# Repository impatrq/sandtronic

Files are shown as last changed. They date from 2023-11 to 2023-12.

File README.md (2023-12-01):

<div align="center">

# **SandTronic**
<div align="center">
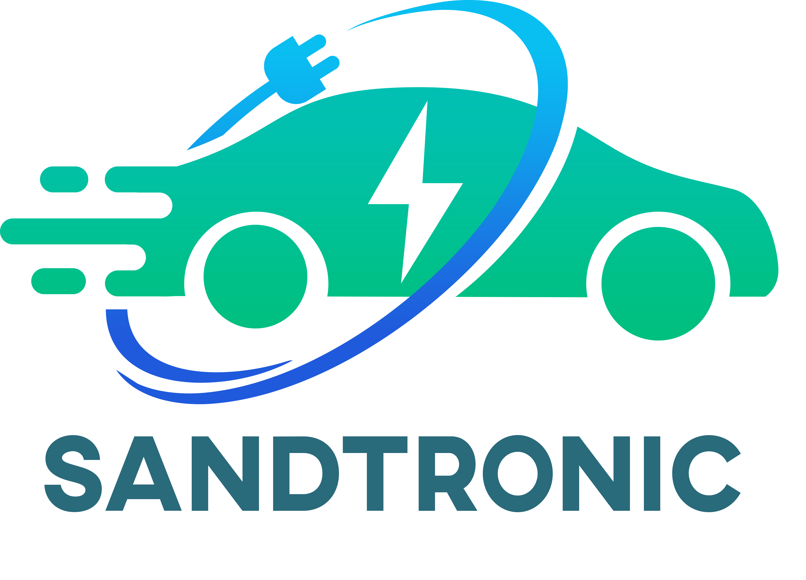
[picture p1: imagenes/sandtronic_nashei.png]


</div>

# ¿Qué es SandTronic?
Es un karting eléctrico especialmente adaptado para su uso en playas, con el propósito de brindar un medio de transporte eficiente y seguro para situaciones de emergencia en las que los guardavidas necesiten rescatar a personas en peligro en el agua o en áreas remotas de la playa.

## ¿Quienes somos?

#### Somos un grupo de estudiantes de aviónica de la E.E.S.T. N°7 "Taller Regional Quilmes", conocida como IMPA.

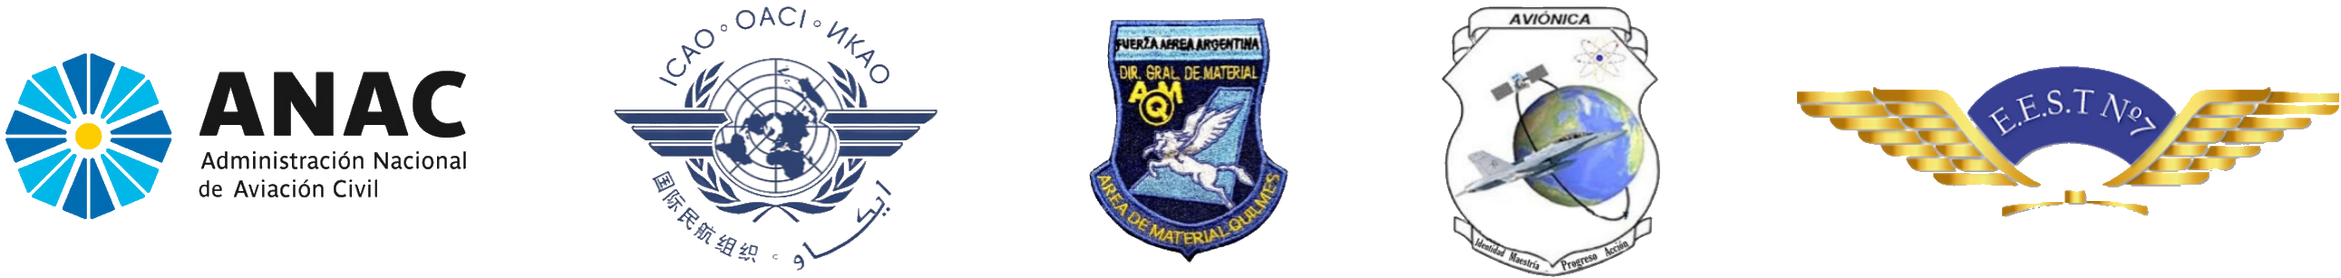
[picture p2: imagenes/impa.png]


# Integrantes

* ###  *Alvarez, Mauricio*
    *    📧 Email: [maurialvarez2004@gmail.com](mailto:maurialvarez2004@gmail.com)         

* ### *Enricci Louzan, Carla*
    *    📧 Email: [carlamicaela2004@gmail.com](mailto:carlamicaela2004@gmail.com)
    *    LinkedIn LinkedIn: [Carla Enricci](https://www.linkedin.com/in/carla-micaela-enricci-louzan/)

* ###  *Morellato, Nicolas*
    *    📧 Email: [morellatonico@gmail.com](mailto:morellatonico@gmail.com)

* ### *Vega Ezequiel*
    *    📧 Email: [ezevega44@gmail.com](mailto:ezevega44@gmail.com)

* ### *Zanichelli, Mateo*
    *  📧 Email: [mateo.zanichelli@hotmail.com](mailto:mateo.zanichelli@hotmail.com)
    *    LinkedIn LinkedIn: [Mateo Zanichelli](https://www.linkedin.com/in/mateo-zanichelli-b1b2b827b/)

<div align="center">
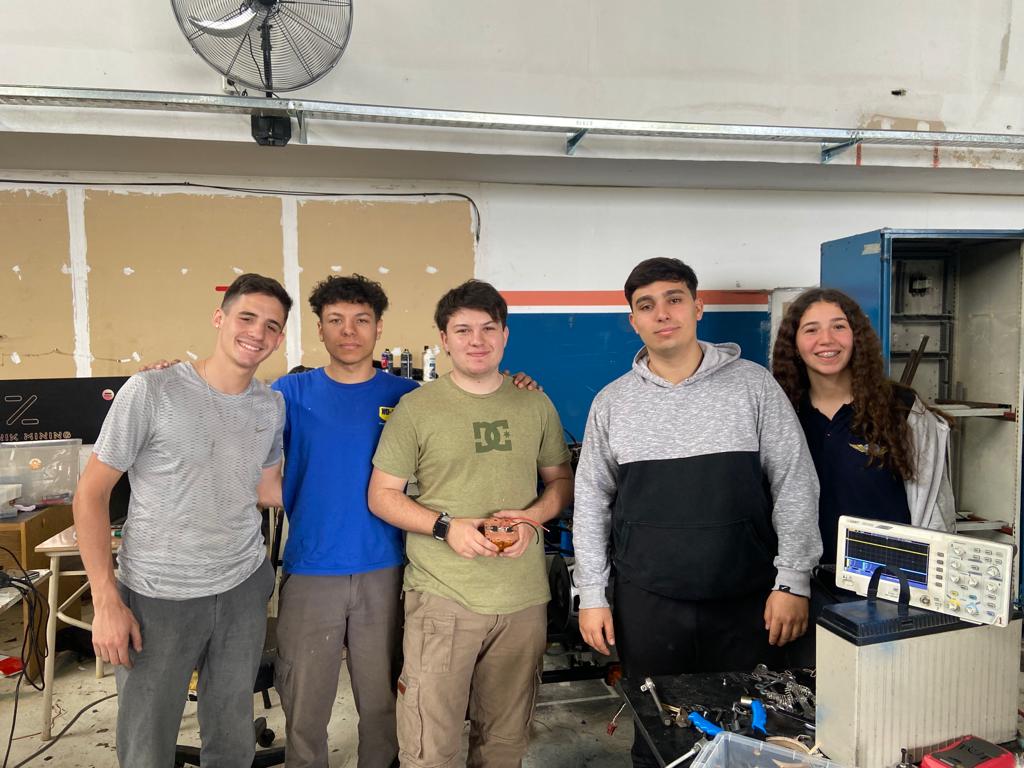
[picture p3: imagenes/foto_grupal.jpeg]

</div>

## ¿Dónde nos pueden encontrar?
### 📷Instagram: [@SandTronic_gr](https://instagram.com/sandtronic_gr?igshid=NzZlODBkYWE4Ng==)
### LinkTree: [SandTronic](https://linktr.ee/sandtronic_gr)
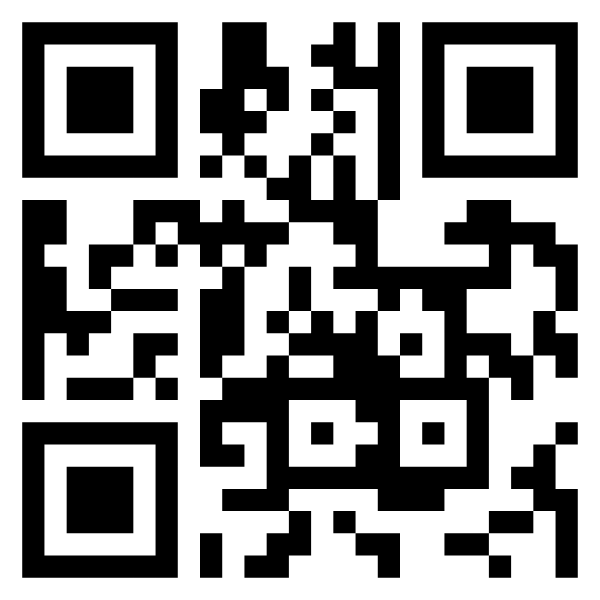
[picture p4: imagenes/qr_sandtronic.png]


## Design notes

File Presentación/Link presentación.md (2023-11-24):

[Dar click para ver presentación](https://www.canva.com/design/DAF0_eJnGpE/yYKZw175jgtaCtqbcVzkhw/view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)

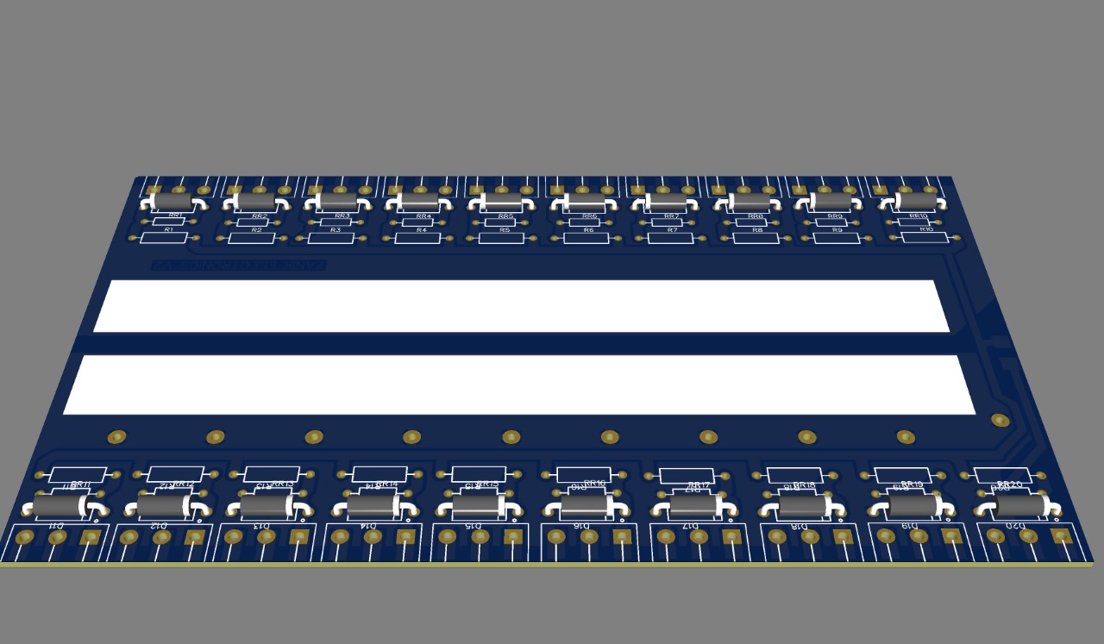
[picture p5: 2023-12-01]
electronica/placa _potencia_3D.jpeg

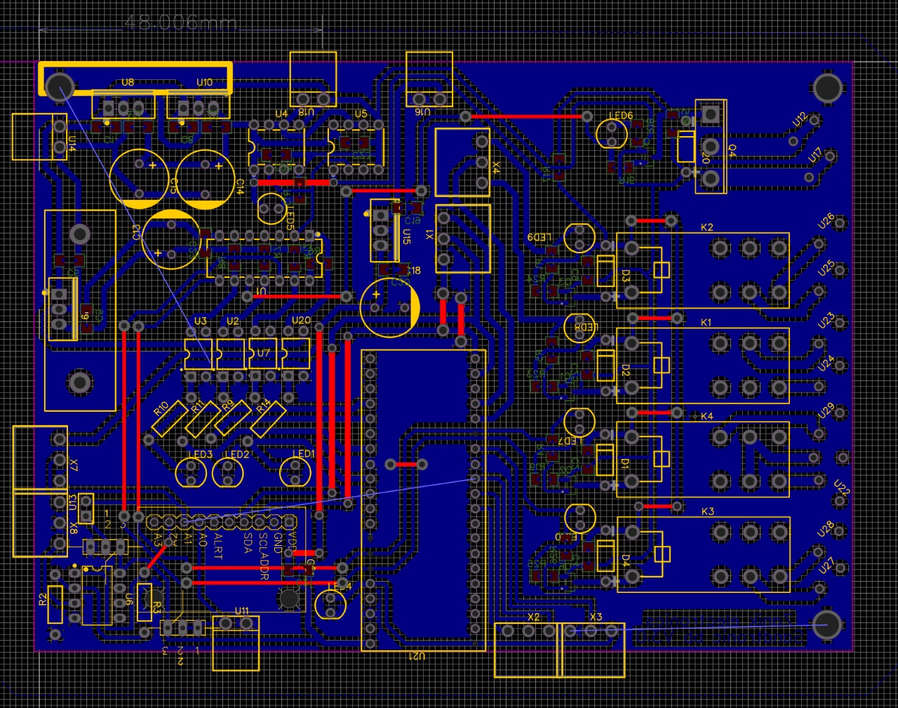
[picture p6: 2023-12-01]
electronica/placa_control_pcb.jpg

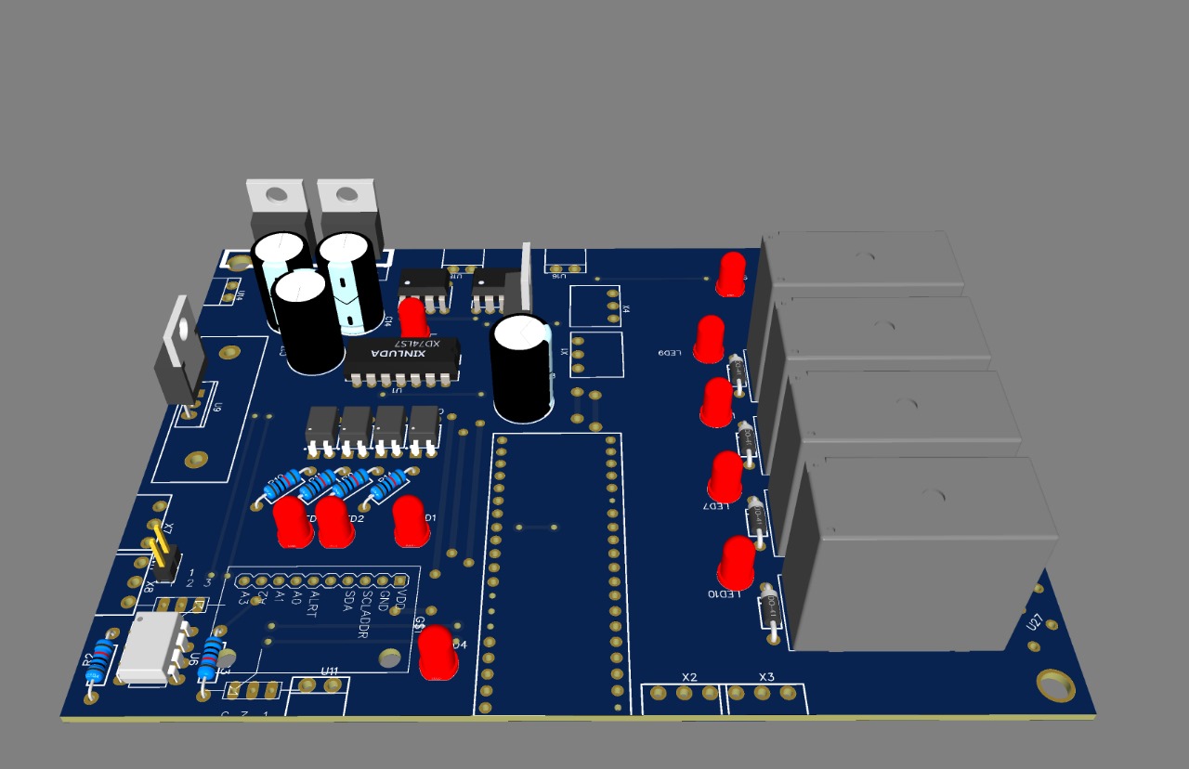
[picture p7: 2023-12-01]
electronica/placa_control_3D.jpeg

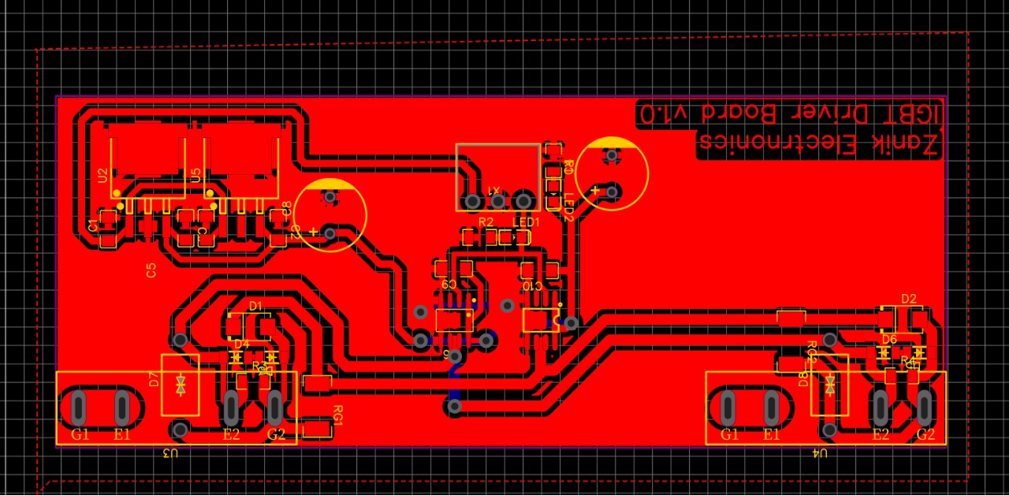
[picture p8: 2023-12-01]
electronica/placa_potencia_pcb.jpg

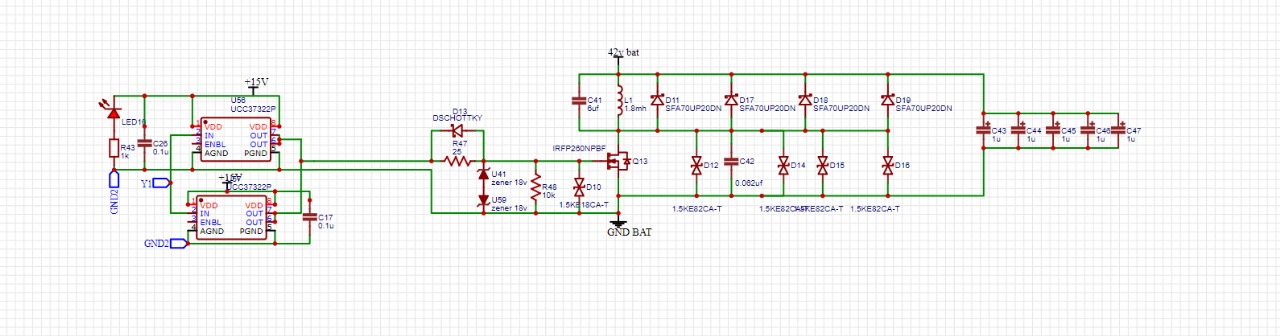
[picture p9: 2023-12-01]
electronica/potencia_schematic_nuevo.jpg

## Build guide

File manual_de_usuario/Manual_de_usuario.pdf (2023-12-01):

# MANUAL DE USUARIO SANDTRONIC

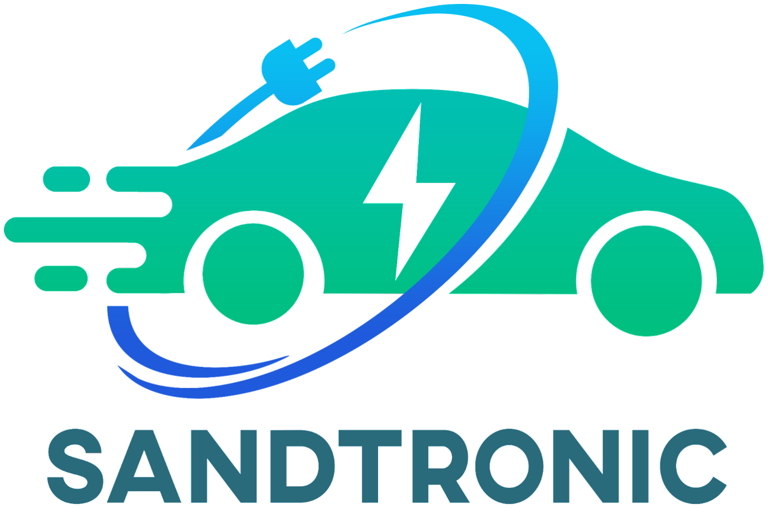
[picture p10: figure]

### E.E.S.T. N°7 “T.R.Q.” Juan B. Justo 79, Quilmes eoffroad2023@gmail.com

2023

# Contenido

I. Introducción
1.Objetivo.

II. Precauciones y seguridad 1.Requerimientos
2.Seguridad

III. Guia de uso

### 1. Encendido del arenero electrico 2. Modos de conducción

I. Introducción

### 1. Objetivo

Principalmente Sandtronic tiene como objetivo diseñar, desarrollar y poner en funcionamiento un karting eléctrico especialmente adaptado para su uso en playas, con el propósito de proporcionar un medio de transporte eficiente y seguro para situaciones de emergencia en las que los guardavidas necesiten rescatar a personas en peligro en el agua o en áreas remotas de la playa.

II.Precauciones y seguridad

### 1. Requerimientos

- Que las baterías se encuentren cargadas (Estas deben tener 12,8V)
- Mantener los ciclos de carga de la batería por encima del 60%
- Evita descargar completamente la batería siempre que sea posible. Las descargas completas frecuentes pueden afectar la vida útil.
- Asegúrate de que el conector de carga esté limpio y en buen estado para garantizar una conexión segura y eficiente.
- Sistema de frenos: Verifica regularmente el estado de los frenos y el nivel del fluido.
- Evita sobrecargas: no sobrecargues la batería, ya que esto puede
dañarla y reducir su vida útil
- Neumáticos: Presión máxima de los neumáticos: 10PSI

### 2. Seguridad

- Instrucciones de Uso: Familiarízate completamente con el manual del usuario y sigue las instrucciones cuidadosamente.
- Equipos de Protección: Siempre usa casco, gafas de protección, guantes y ropa adecuada al andar en el arenero.
- Supervisión: Se recomienda supervisión de alguien con experiencia mientras un conductor inexperto utiliza el arenero.
- Mantenimiento Regular: Realiza revisiones periódicas y mantenimiento según las indicaciones del manual para garantizar un rendimiento seguro.
- Carga Máxima: Respete la capacidad de carga máxima del vehículo(220KG).

III. Guia de uso

### 1. Encendido del arenero electrico

A- Inspección Previa:

Antes de cada uso, realiza una inspección visual del arenero para asegurarte de que no haya daños visibles. Verifica que los neumáticos estén inflados correctamente.

B- Ajustes del Asiento y Cinturón de Seguridad:

Ajusta el asiento a una posición cómoda y asegúrase de abrocharse el cinturón de seguridad antes de comenzar la conducción

C- Encendido:

Mantenga pulsado el botón START durante tres segundos, luego ponga el interruptor en ON

D- Arranque Suave:

Al iniciar, presione el acelerador suavemente para evitar arranques bruscos. Familiarízate con la respuesta del vehículo.

E- Maniobras Seguras:

Evitar giros bruscos y maniobras riesgosas. Aprende a girar y maniobrar de manera controlada.

F- Carga y Capacidad

Respeta la capacidad de carga máxima especificada en el manual del usuario(220KG).
Distribuye la carga de manera uniforme para mantener la estabilidad.

### 2. Modos de conducción

Sandtronic cuenta con dos modos de conducción

MODO SPORT: En este modo el karting tiene una autonomía de 28 KM

MODO ECO: En este modo el karting tiene una autonomía de 42 KM

Ambos modos lo podremos seleccionar con una llave selectora que se encuentra a la izquierda del tablero.

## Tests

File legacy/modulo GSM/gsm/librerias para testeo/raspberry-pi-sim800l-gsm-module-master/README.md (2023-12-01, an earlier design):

# Raspberry Pi SIM800L GSM module






[SIM800L GSM module](https://www.simcom.com/product/SIM800.html) library for Linux systems like the Raspberry Pi.

This library interfaces the SIM800L GSM device and allows sending, receiving and deleting SMS messages, as well as performing HTTP GET/POST requests, synching/updating the RTC and getting other information from the module.

## Setup

## Hw Requirements
- Linux system with a UART serial port, or Raspberry Pi with [Raspberry Pi OS](https://en.wikipedia.org/wiki/Raspberry_Pi_OS) (this library has been tested with Buster and Bullseye).
- External power supply for the SIM800L (using the Raspberry Pi 5V power supply, a standard diode (1N4007) with voltage drop of about 0.6 volts and a 2200 uF capacitor might work).

### Installation

Check that the [Python](https://www.python.org/) version is 3.6 or higher (`python3 -V`), then install the *sim800l-gsm-module* with the following command:

```shell
python3 -m pip install sim800l-gsm-module
```

Prerequisite components: *pyserial*, *gsm0338*. All needed prerequisites are automatically installed with the package.

Alternatively to the above mentioned installation method, the following steps allow installing the latest version from GitHub.

- Optional preliminary configuration (if not already done):

  ```shell
  sudo apt-get update
  sudo apt-get -y upgrade
  sudo add-apt-repository universe # this is only needed if "sudo apt install python3-pip" fails
  sudo apt-get update
  sudo apt install -y python3-pip
  python3 -m pip install --upgrade pip
  sudo apt install -y git
  ```

- Run this command:

```shell
  python3 -m pip install git+https://github.com/Ircama/raspberry-pi-sim800l-gsm-module
```

To uninstall:

```shell
python3 -m pip uninstall -y sim800l-gsm-module
```

### Hardware connection

sim800l

### Disabling the serial console login

Disabling the serial console login is needed in order to enable communication between the Raspberry Pi and SIM800L via /dev/serial0.

- Open the terminal on your pi and run `sudo raspi-config` 
- Select Interfaces → Serial 
- Select No to the 1st prompt and Yes for the 2nd one.

## Basic use

Check [Usage examples](#usage-examples). Basic program:

```python 
from sim800l import SIM800L
sim800l = SIM800L()
sim800l.setup()
print("Unit Name:", sim800l.get_unit_name())
```

## API Documentation

Tested with SIM800L firmware Revision:[1418B05SIM800L24](https://github.com/geekmatic/SIM800_firmware_updates) (SIM800L R14.18, Build 05).

SIM800 does not support AT+HTTPSSL on firmware release <R14.00 (e.g., 1308B08SIM800L16 -> SIM800L R13.08 Build 08).

For debugging needs, logs can be set to the maximum level (verbose mode, tracing each request/response) with the following command:

```python
import logging
logging.getLogger().setLevel(5)`
```

---

#### `sim800l = SIM800L(port='/dev/serial0', baudrate=115000, timeout=3.0)`
Class instantiation (using [pySerial](https://github.com/pyserial/pyserial))
- `port`: port name
- `baudrate`: baudrate in bps
- `timeout`: timeout in seconds

---

#### `check_sim()`
Check whether the SIM card has been inserted.
 *return*: `True` if the SIM is inserted, otherwise `False`. `None` in case of module error.

---

#### `command(cmdstr, lines=1, waitfor=500, msgtext=None, flush_input=True)`
Executes an AT command. A newline must be added at the end of the AT command (e.g., `sim800l.command("AT+CCLK?\n", lines=-1)`).
Input is flushed before sending the command (`flush_input=False` disables flushing).
The first newline is discarded (if `lines` != 0).
- `cmdstr`: AT command string
- `lines`: number of expexted lines (see below)
- `waitfor`: number of (milliseconds - 1000) to wait for the returned data; not used if <= 1000 milliseconds.
- `msgtext`: only to be used when sending SMS messages, it includes the SMS text.
- `flush_input`: `True` if residual input is flushed before sending the command. `False` disables flushing.

 *return*: the first line is returned (string); use `check_incoming()` to read the subsequent lines. `None` is returned when no data is received (or module error).

If `lines=0`, terminates just after writing text to the device (no bytes read; no return code, e.g. `None` returned). Note: `check_incoming()` can be subsequently used to read data from the device (see subsequent example).

If `lines`<0 (e.g., `lines=-1`), return the concatenation of all read lines (until pySerial timeout `sim800l.serial_port().timeout`), separating each line by a linefeed.

If `lines`>1 (legacy code), return the concatenation of all read lines, separating each line by a linefeed, discarding null lines and "OK".

Example:

```python
import time
from sim800l import SIM800L

sim800l=SIM800L('/dev/serial0')

# Send data and return the first line
print(sim800l.command("AT+CCLK?\n"))  # ...+CCLK...

# Same as before, but reading both lines
sim800l.command("AT+CCLK?\n", lines=0)  # send AT command without reading data
print("First read line:", sim800l.check_incoming())  # ...+CCLK...
print("Second read line:", sim800l.check_incoming())  # ...'OK'...

# Same as before, but more elaborated
sim800l.command("AT+CCLK?\n", lines=0)
expire = time.monotonic() + 2  # seconds
sequence = ""
s = sim800l.check_incoming()
date = None
while time.monotonic() < expire:
    if s[0] == 'GENERIC' and s[1] and s[1].startswith('+CCLK: "'):
        date = s[1].split('"')[1]
        sequence += "D"
    if s == ('OK', None):
        sequence += "O"
    if sequence == "DO":
        print("Date:", date)
        break
    time.sleep(0.1)
    s = sim800l.check_incoming()

if not date:
    print("Error")
```

---

#### `command_data_ok(cmd, attempts=2)`
Send AT command to the device, read the answer and then check the
existence of the OK message. "cmd" shall not have the ending newline.
- `cmd`: AT command
- `attempts`: number of attempts before returning None or False
 *return*: string in case of successful retrieval; otherwise None if module error or False if missing OK message

---

#### `command_ok(cmd, check_download=False, check_error=False, cmd_timeout=10, attempts=2)`
Send AT command to the device and check that the return sting is OK.
Newline must not be put at the end of the string.
- `cmd`: AT command
- `check_download`: `True` if the “DOWNLOAD” return sting has to be checked
- `check_error`: `True` if the “ERROR” return sting has to be checked
- `cmd_timeout`: timeout in seconds
- `attempts`: number of attempts before returning False
 *return*: `True` = OK received, `False` = OK not received (or module error). If check_error, can return `ERROR`; if check_download, can return `DOWNLOAD`

---

#### `connect_gprs(apn=None)`
Connect to the bearer and get the IP address of the PDP context.
Automatically perform the full PDP context setup.
Reuse the IP session if an IP address is found active.
- `apn`: APN name
 *return*: `False` if error (including module error), otherwise return the IP address (as string)

---

#### `delete_sms(index_id)`
Delete the SMS message referred to the index
- `index_id`: index in the SMS message list starting from 1
 *return*: `None`

---

#### `disconnect_gprs(apn=None)`
Disconnect the bearer.
 *return*: `True` if succesfull, `False` if error

---

#### `get_battery_voltage()`
Return the battery voltage in Volts
 *return*: floating (volts). `None` in case of module error.

Example: 4.158

---

#### `get_ccid()`
Get the ICCID
 *return*: string; `None` in case of module error.

Example: "1122334455667788990f"

---

#### `get_date()`
Return the clock date available in the module.
 *return*: `datetime.datetime`; `None` in case of module error.

Example: "2022-03-09 19:59:31"

---

#### `get_flash_id()`
Get the SIM800 GSM module flash ID
 *return*: string; `None` in case of module error.

Example: "Device Name:SERIAL§FLASH§MTKSIP§6261§SF§24§01"

---

#### `get_hw_revision()`
Get the SIM800 GSM module hw revision
 *return*: string; `None` in case of module error.

Example: "Revision:1418B05SIM800L24"

---

#### `get_imsi()`
Get the IMSI
 *return*: string; `None` in case of module error.

Example: "112233445566778"

---

#### `get_ip()`
Get the IP address of the PDP context
 *return*: valid IP address string if the bearer is connected, otherwise `None` (e.g., module error).

---

#### `get_msgid()`
Return the unsolicited notification of incoming SMS
 *return*: number

---

#### `get_msisdn()`
Get the MSISDN subscriber number
 *return*: string. `None` in case of module error.

---

#### `get_operator()`
Display the current network operator that the handset is currently
registered with.
 *return*: operator string. `None` in case of module error. `False` in case of SIM error.

Example: "Vodafone"

---

#### `get_operator_list()`
Display a full list of network operator names.
 *return*: dictionary of "numeric: "name" fields; None in case of error.

---

#### `get_serial_number()`
Get the SIM800 GSM module serial number
 *return*: string; `None` in case of module error.

Example: "866782042319455"

---

#### `get_service_provider()`
Get the Get Service Provider Name stored inside the SIM
 *return*: string. `None` in case of module error. `False` in case of SIM error.

---

#### `get_signal_strength()`
Get the signal strength
 *return*: number; min = 3, max = 100; `None` in case of module error.

Example: 40.625

---

#### `get_temperature()`
Get the SIM800 GSM module temperature in Celsius degrees
 *return*: string; `None` in case of module error.

Example: "24.21"

---

#### `get_unit_name()`
Get the SIM800 GSM module unit name
 *return*: string (e.g., "SIM800 R14.18"); `None` in case of module error.

---

#### `hard_reset(reset_gpio)`
Perform a hard reset of the SIM800 module through the RESET pin.
This function can only be used on a Raspberry Pi.
- `reset_gpio`: RESET pin
 *return*: `True` if the SIM is active after the reset, otherwise `False`. `None` in case of module error.

---

#### `http(url="...", data="...", apn="...", method="...", use_ssl=False, ua=None, content_type="application/json", allow_redirection=False, http_timeout=10, keep_session=False, attempts=2)`
Run the HTTP GET method or the HTTP PUT method and return retrieved data
Automatically perform the full PDP context setup and close it at the end
(use keep_session=True to keep the IP session active). Reuse the IP
session if an IP address is found active.
Automatically open and close the HTTP session, resetting errors.
- `url`: URL
- `data`: input data used for the PUT method (bytes; e.g., use `data="string".encode()`)
- `apn`: APN name
- `method`: "GET" or "PUT"
- `use_ssl`: `True` if using HTTPS, `False` if using HTTP (see note)
- `ua`: User agent (string); is not set, the SIM800L default user agent is used ("SIMCOM_MODULE").
- `content_type`: (string) set the "Content-Type" field in the HTTP header
- `allow_redirection`: `True` if HTTP redirection is allowed (e.g., if the server sends a redirect code (range 30x), the client will automatically send a new HTTP request)
- `http_timeout`: timeout in seconds
- `keep_session`: `True` to keep the PDP context active at the end
- `attempts`: number of attempts before returning False
 *return*: `False` if error, otherwise the returned data (as string)

While the *Content type* header field can be set, the *Content encoding* is always null.

Sending data with [zlib](https://docs.python.org/3/library/zlib.html) is allowed:

```python
import zlib
body = zlib.compress('hello world'.encode())
sim800l.http("...url...", method="PUT", content_type="zipped", data=body, apn="...")
```

[Note on SSL](https://github.com/ostaquet/Arduino-SIM800L-driver/issues/33#issuecomment-761763635): SIM800L datasheets report that the embedded IP stack only supports SSL2, SSL3 and TLS 1.0. These cryptographic protocols are deprecated for all modern backend servers and the connection will be generally denied by the server, typically leading to SIM800L error 605 or 606 when establishing an HTTPS connection. Some SIM800L datasheets also report support of TLS 1.2 but this does not appear to be true with firmware Revision 1418B05SIM800L24.  So, using `use_ssl=True` is discouraged; setting a Python web server to support the SSL option of a SIM800L client module is not straightforward (it is better to use an [application encryption](https://stackoverflow.com/a/55147077/10598800) instead of SSL). Generally, to be able to connect an HTTPS web service, a separate proxy server is needed (e.g., a custom Python application in cloud), receiving non-SSL HTTP requests from the SIM800L module (possibly with application encryption) and forwarding them to the AWS Lambda HTTP API gateway via HTTPS.

Notice also that, depending on the web server, a specific SSL certificate could be needed for a successful HTTPS connection; the SIM800L module has a limited support of SSL certificates and [installing an additional one](https://stackoverflow.com/questions/36996479/how-sim800-get-ssl-certificate
) is not straightforfard.

An additional problem is related to possible DNS errors when accessing endpoints. Using IP addresses is preferred.

---

#### `internet_sync_time(time_server='193.204.114.232', time_zone_quarter=4, apn=None, http_timeout=10, keep_session=False)`
Connect to the bearer, get the IP address and sync the internal RTC with
the local time returned by the NTP time server (Network Time Protocol).
Automatically perform the full PDP context setup.
Disconnect the bearer at the end (unless keep_session = `True`)
Reuse the IP session if an IP address is found active.
- `time_server`: internet time server (IP address string)
- `time_zone_quarter`: time zone in quarter of hour
- `http_timeout`: timeout in seconds
- `keep_session`: `True` to keep the PDP context active at the end
 *return*: `False` if error, otherwise the returned date (`datetime.datetime`)

Example: "2022-03-09 20:38:09"

---

#### `query_ip_address(url=None, apn=None, http_timeout=10, keep_session=False)`
Connect to the bearer, get the IP address and query an internet domain
name, getting the IP address.
Automatically perform the full PDP context setup.
Disconnect the bearer at the end (unless keep_session = `True`)
Reuse the IP session if an IP address is found active.
- `url`: internet domain name to be queried
- `http_timeout`: timeout in seconds
- `keep_session`: True to keep the PDP context active at the end
 *return*: `False` if error (`None` for module error), otherwise the returned IP address (string)

---

#### `is_registered()`
Check whether the SIM is Registered, home network
 *return*: Truse if registered, otherwise `False`. . `None` in case of module error.

---

#### `read_and_delete_all(index_id=1)`
Read the message at position 1, otherwise delete all SMS messages, regardless the type (read, unread, sent, unsent, received).
If the message is succesfully retrieved, no deletion is done. (Deletion only occurs in case of retrieval error.)
Notice that, while generally message 1 is the first to be read, it might happen that no message at position 1 is available,
while other positions might still include messages; for those cases (missing message at position 1, but other messages
available at other positions), the whole set of messages is deleted.
Use `index_id=0` to delete all messages without trying to retrieve the one at position 1.
 *return*: text of the read message

---

#### `read_next_message(all_msg=False)`
Check messages, read one message and then delete it. This function can be repeatedly called to read all stored/received messages one by one and delete them.
- `all_msg`: `True` if no filter is used (read and unread messages).  Otherwise only the unread messages are returned.
 *return*: retrieved message text (string), otherwise: `None` = no messages to read; `False` = read error (module error)

---

#### `read_sms(index_id)`
Read the SMS message referred to the index_id position
- `index_id`: index in the SMS message list starting from 1
 *return*: `None` if error, otherwise return a tuple including: MSISDN origin number, SMS date string, SMS time string, SMS text

---

#### `send_sms(destno, msgtext)`
Send SMS message
- `destno`: MSISDN destination number
- `msgtext`: Text message
 *return*: `True` if message is sent, otherwise `False`

---

#### `serial_port()`
Return the serial port (for direct debugging)
 *return*:

---

#### `set_date()`
Set the Linux system date with the GSM time
 *return*: date string. `None` in case of module error.

Example: "2022-03-09 20:10:54"

---

#### `setup()`
Run setup strings for the initial configuration of the SIM800 module
 *return*: `True` if setup is successfully completed; `None` in case of module error.

---

#### `sim800l.convert_gsm(string)`
Encode `string` to bytes using the 3GPP TS 23.038 / ETSI GSM 03.38 codec.
- `string`: UTF8 string
 *return*: gsm03.38 bytes

---

#### `sim800l.convert_to_string(buf)`
Decode GSM 03.38 encoded bytes, returning a string.
- `buf`: gsm03.38 bytes
 *return*: UTF8 string

---

#### `check_incoming()`
Internal function, used to check incoming data from the SIM800L module, decoding messages.
It also fires the functions configured with `callback_msg()` and `callback_no_carrier()`.
 *return*: tuple

Return values:
- `('GENERIC', None)`: no data received
- `('GENERIC', data)`: received data is returned (`data` is a string)
- `("HTTPACTION_PUT", False, size)`: invalid HTTP PUT method, with return code different from 200
- `("HTTPACTION_PUT", True, size)`: valid HTTP PUT method; `size` is the number of returned characters
- `("HTTPACTION_GET", False, size)`: invalid HTTP GET method, with return code different from 200
- `("HTTPACTION_GET", True, size)`: valid HTTP GET method; `size` is the number of returned characters
- `("IP", "ip address")`: bearer connected, received IP address
- `("IP", None)`: Disconnected
- `("CMTI", index_id)`: received SMS message with index `index_id`
- `("NOCARRIER", None)`: "NO CARRIER" message detected
- `("RING", None)`: "RING" message detected
- `("OK", None)`: "OK" message detected
- `("DOWNLOAD", None)`: "DOWNLOAD" message detected
- `("ERROR", None)`: "ERROR" message detected
- `("DNS", None, error)`: DNS error message
- `("DNS", dns1, dns2)`: IP address and FQDN retrieved from the DNS
- `("NTP", None, error)`: NTP query error
- `("NTP", date, 0)`: Successful NTP query; `date` is `datetime.datetime` format
- `("COPN", numeric, name)`: Operator number and name
- `("CREG", numeric)`: Registration status
- `("CTZV", tz1, tz2)`: Time Zone
- `("PSUTTZ", year, month, day, hour, minute, second, tz1, tz2)`: time and time zone
- `("DST", dst)`: Daylight Saving Time
- `("RDY", None)`: Power procedure completed
- `("CFUN", numeric)`: Phone functionality indication
- `("PIN", pin)`: PIN
- `("MSG", "Call Ready)`: Call ready
- `("MSG", "SMS Ready)`: SMS ready

Usage sample 1:
```python
if self.check_incoming() != ("OK", None):
    print("Error")
```

---

#### `get_clip()`
(legacy code, not used)

---

#### `set_charset_hex()`
Set the module to the HEX character set (only hexadecimal values from 00 to FF)
 *return*: "OK" if successful, otherwise `None` in case of module error.

---

#### `set_charset_ira()`
Set the module to the International reference alphabet (ITU-T T.50) character set
 *return*: "OK" if successful, otherwise `None` in case of module error.

---

#### `callback_incoming(function)`
(legacy code, not used)
- `function`: Python function with no args

---

#### `callback_msg(function)`
(legacy code)
Configure a callback function, fired when `check_incoming()` receives a message (`+CMTI` returned, indicating new message received).
- `function`: Python function with no args

---

#### `callback_no_carrier(function)`
(legacy code)
Configure a callback function, fired when `check_incoming()` receives "NO CARRIER".
- `function`: Python function with no args

---

## Usage examples

```python 
from sim800l import SIM800L
sim800l = SIM800L('/dev/serial0')
```

#### Return module information
```python
from sim800l import SIM800L

sim800l = SIM800L()
sim800l.setup()

print("Date:",
    sim800l.get_date())
print("Operator:",
    sim800l.get_operator())
print("Service provider:",
    sim800l.get_service_provider())
print("Signal strength:",
    sim800l.get_signal_strength(), "%")
print("Temperature:",
    sim800l.get_temperature(), "degrees")
print("MSISDN:",
    sim800l.get_msisdn())
print("Battery Voltage:",
    sim800l.get_battery_voltage(), "V")
print("IMSI:",
    sim800l.get_imsi())
print("ICCID:",
    sim800l.get_ccid())
print("Unit Name:",
    sim800l.get_unit_name())

if sim800l.is_registered():
    print("SIM is registered.")
else:
    print("SIM NOT registered.")
```

#### Sync time with internet
```python
sim800l.internet_sync_time(apn="...", time_zone_quarter=...)
```

#### Query the DNS for an internet name
```python
sim800l.query_ip_address(url="httpbin.org", apn="...")
```

#### Hard reset
```python
# Note: connect the RST pin with GPIO23 (pin 16 of the Raspberry Pi)
sim800l.hard_reset(23)  # see schematics
```

#### Send SMS
```python
sms="Hello there"
#sim800l.send_sms(dest.no,sms)
sim800l.send_sms('2547xxxxxxxx',sms)
```

#### Read the next SMS message
```python
msg = sim800l.read_next_message(all_msg=True)
```

#### HTTP GET samples
```python
print(sim800l.http("httpbin.org/ip", method="GET", apn="..."))
print(sim800l.http("httpbin.org/get", method="GET", use_ssl=False, apn="..."))  # HTTP
print(sim800l.http("httpbin.org/get", method="GET", use_ssl=True, apn="..."))  # HTTPS
```

Note: time ago `httpbin.org` succeeded with HTTPS because supporting an old SSL version. Curently the test fails with HTTPS.

#### HTTP PUT sample
```python
print(sim800l.http("httpbin.org/post", data='{"name","abc"}'.encode(), method="PUT", apn="..."))  # HTTPS
print(sim800l.http("httpbin.org/post", data='{"name","abc"}'.encode(), method="PUT", use_ssl=False, apn="..."))  # HTTP
```

#### Read the n-th SMS
```python
Read the SMS indexed by the index_id value [ref. also check_incoming()]
index_id=...  # e.g., 1
sim800l.read_sms(index_id)
```

#### Callback action
(legacy code)
```python
def print_delete():
    # Assuming the SIM has no SMS initially
    sms = sim800l.read_sms(1)
    print(sms)
    sim800l.delete_sms(1)

sim800l.callback_msg(print_delete)

while `True`:
    sim800l.check_incoming()
```

## References
- [AT Datasheet](https://microchip.ua/simcom/2G/SIM800%20Series_AT%20Command%20Manual_V1.12.pdf)
- [Application notes](https://www.microchip.ua/simcom/?link=/2G/Application%20Notes)
- [Specifications](https://simcom.ee/documents/?dir=SIM800L)

Arduino:
- https://github.com/vshymanskyy/TinyGSM
- https://lastminuteengineers.com/sim800l-gsm-module-arduino-tutorial/

## History
This library is a fork of https://github.com/jakhax/raspberry-pi-sim800l-gsm-module with many additions.

The backward compatibility with the original repo is still kept.

> SIM900/SIM800 are 2G only modems, make sure your provider supports 2G as it is already being phased out in a lot of areas around the world, else a 3G/4G modem like the SIM7100 / SIM5300 is warranted.

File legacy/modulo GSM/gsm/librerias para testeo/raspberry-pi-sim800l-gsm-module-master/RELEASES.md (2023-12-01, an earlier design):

# Release process

Only tags are used by now (not releases).

# Tagging a release

If a version needs to be changed, edit `sim800l/__version__.py`.

This file is read by *setup.py*.

If the version is not changed, the publishing procedure works using the same version with a different build number.

The GITHUB_RUN_NUMBER environment variable, when available, is read by *setup.py*.

Push all changes:

```shell
git commit -a
git push
```

_After pushing the last commit_, add a local tag (shall be added AFTER the commit that needs to be published):

```shell
git tag # list local tags
git tag v0.1.4
```

Notes:

- correspondence between tag and `__version__.py` is not automatic.
- the tag must start with "v" if a GitHub Action workflow needs to be run

Push this tag to the origin, which starts the PyPI publishing workflow (GitHub Action):

```shell
git push origin v0.1.4
git ls-remote --tags https://github.com/Ircama/raspberry-pi-sim800l-gsm-module # list remote tags
```

Check the published tag here: https://github.com/Ircama/raspberry-pi-sim800l-gsm-module/tags

It shall be even with the last commit.

Check the GitHub Action: https://github.com/Ircama/raspberry-pi-sim800l-gsm-module/actions

Check PyPI:

- https://test.pypi.org/manage/project/sim800l-gsm-module/releases/
- https://pypi.org/manage/project/sim800l-gsm-module/releases/

End user publishing page:

- https://test.pypi.org/project/sim800l-gsm-module/
- https://pypi.org/project/sim800l-gsm-module/

Verify whether wrong builds need to be removed.

Test installation:

```shell
cd
python3 -m pip uninstall -y sim800l-gsm-module
python3 -m pip install sim800l-gsm-module
python3
from sim800l import SIM800L
quit()
python3 -m pip uninstall -y sim800l-gsm-module
```

# Updating the same tag (using a different build number for publishing)

```shell
git tag # list tags
git tag -d v1.0.0 # remove local tag
git push --delete origin v1.0.0 # remove remote tag
git ls-remote --tags https://github.com/Ircama/raspberry-pi-sim800l-gsm-module # list remote tags
```

Then follow the tagging procedure again to add the tag to the latest commit.

# Testing the build procedure locally

```shell
cd <repository directory>
```

## Local build (using build):

```shell
python3 -m build --sdist --wheel --outdir dist/ .
python3 -m twine upload --repository testpypi dist/*
```

(change *testpypi*)

## Local build (using setup):

```shell
python3 setup.py sdist bdist_wheel
python3 -m twine upload --repository testpypi dist/*
```

(change *testpypi*)

## Local build (using build versions):

```shell
GITHUB_RUN_NUMBER=31 python3 setup.py sdist bdist_wheel
python3 -m twine upload --repository testpypi dist/*
```

(change *testpypi*)

## Removing directories

```shell
ls -l dist
rm -r build dist sim800l_gsm_module.egg-info
```

# Check version data

- https://pypi.org/pypi/sim800l-gsm-module/json
- https://test.pypi.org/pypi/sim800l-gsm-module/json

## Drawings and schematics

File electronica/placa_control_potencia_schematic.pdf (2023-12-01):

## A2 GND

## GND

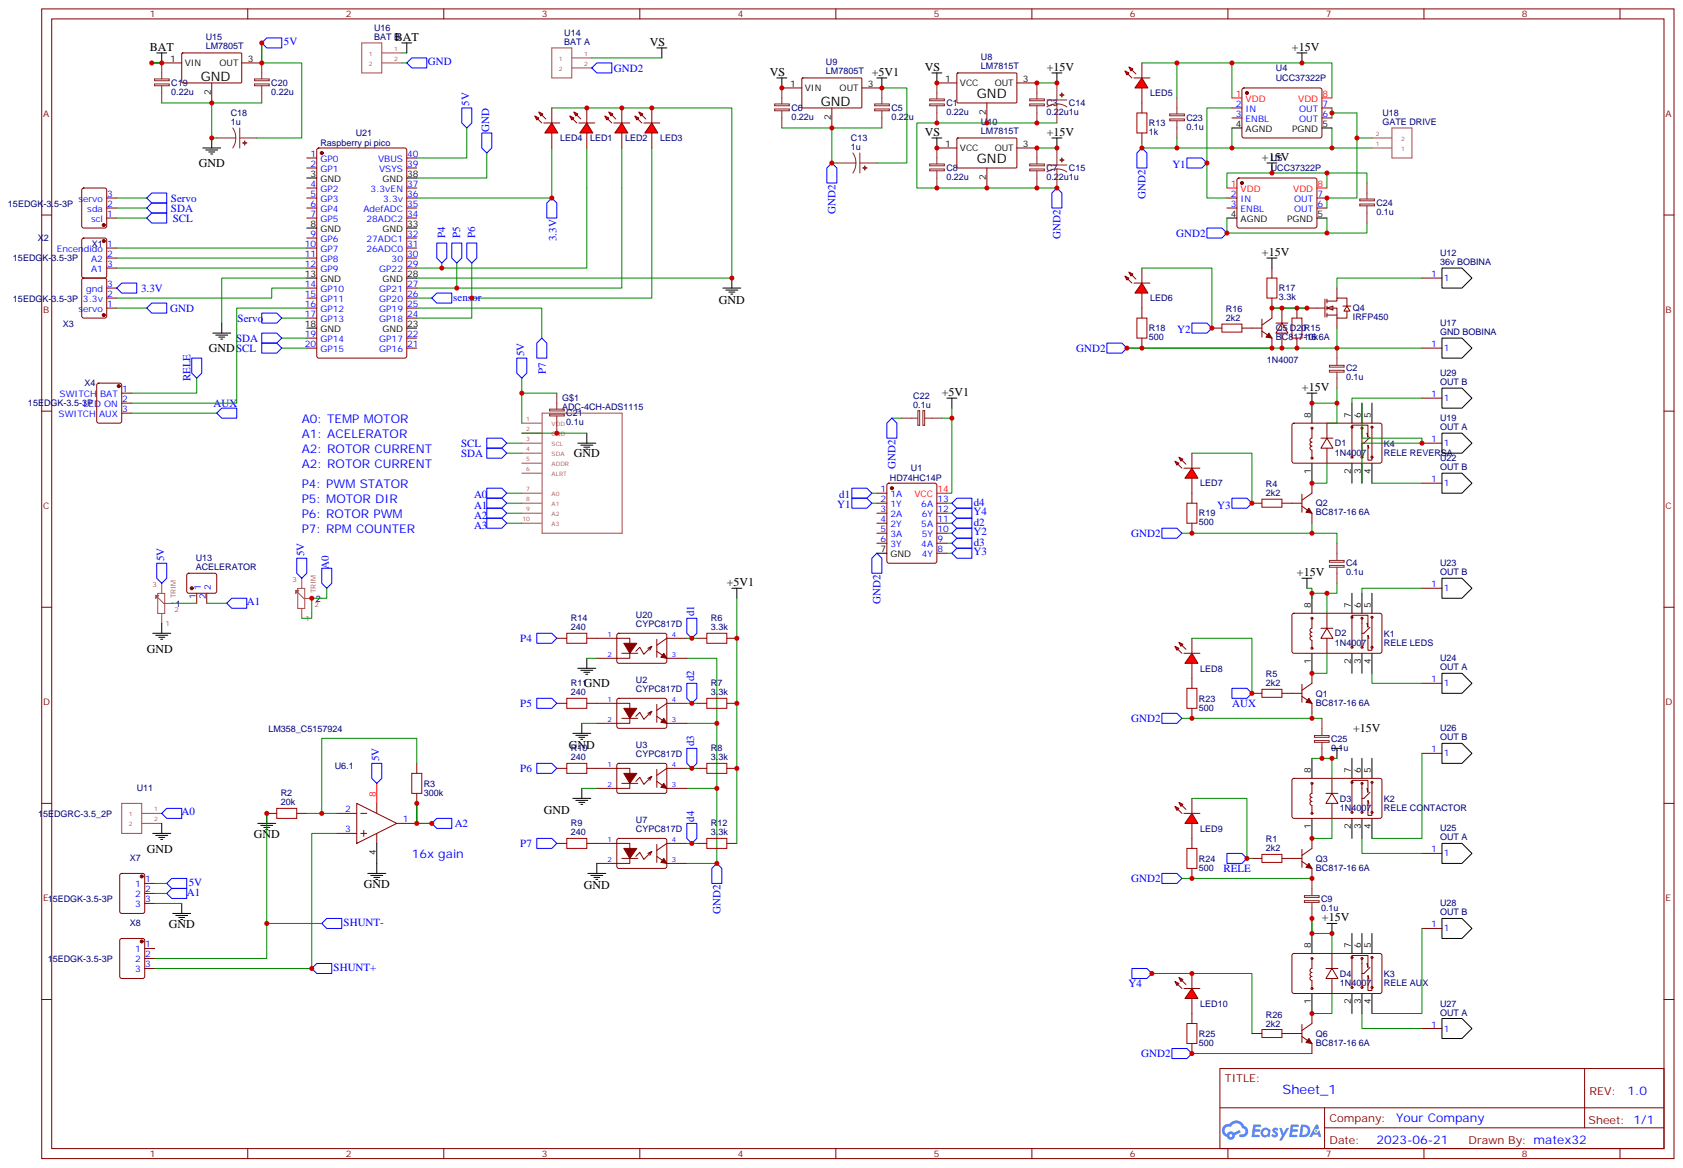
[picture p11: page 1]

A | A
B | B
C | C
D | D

TITLE:
Sheet_1 | REV: 1.0
Date: | 2023-11-07

## GND

## GND

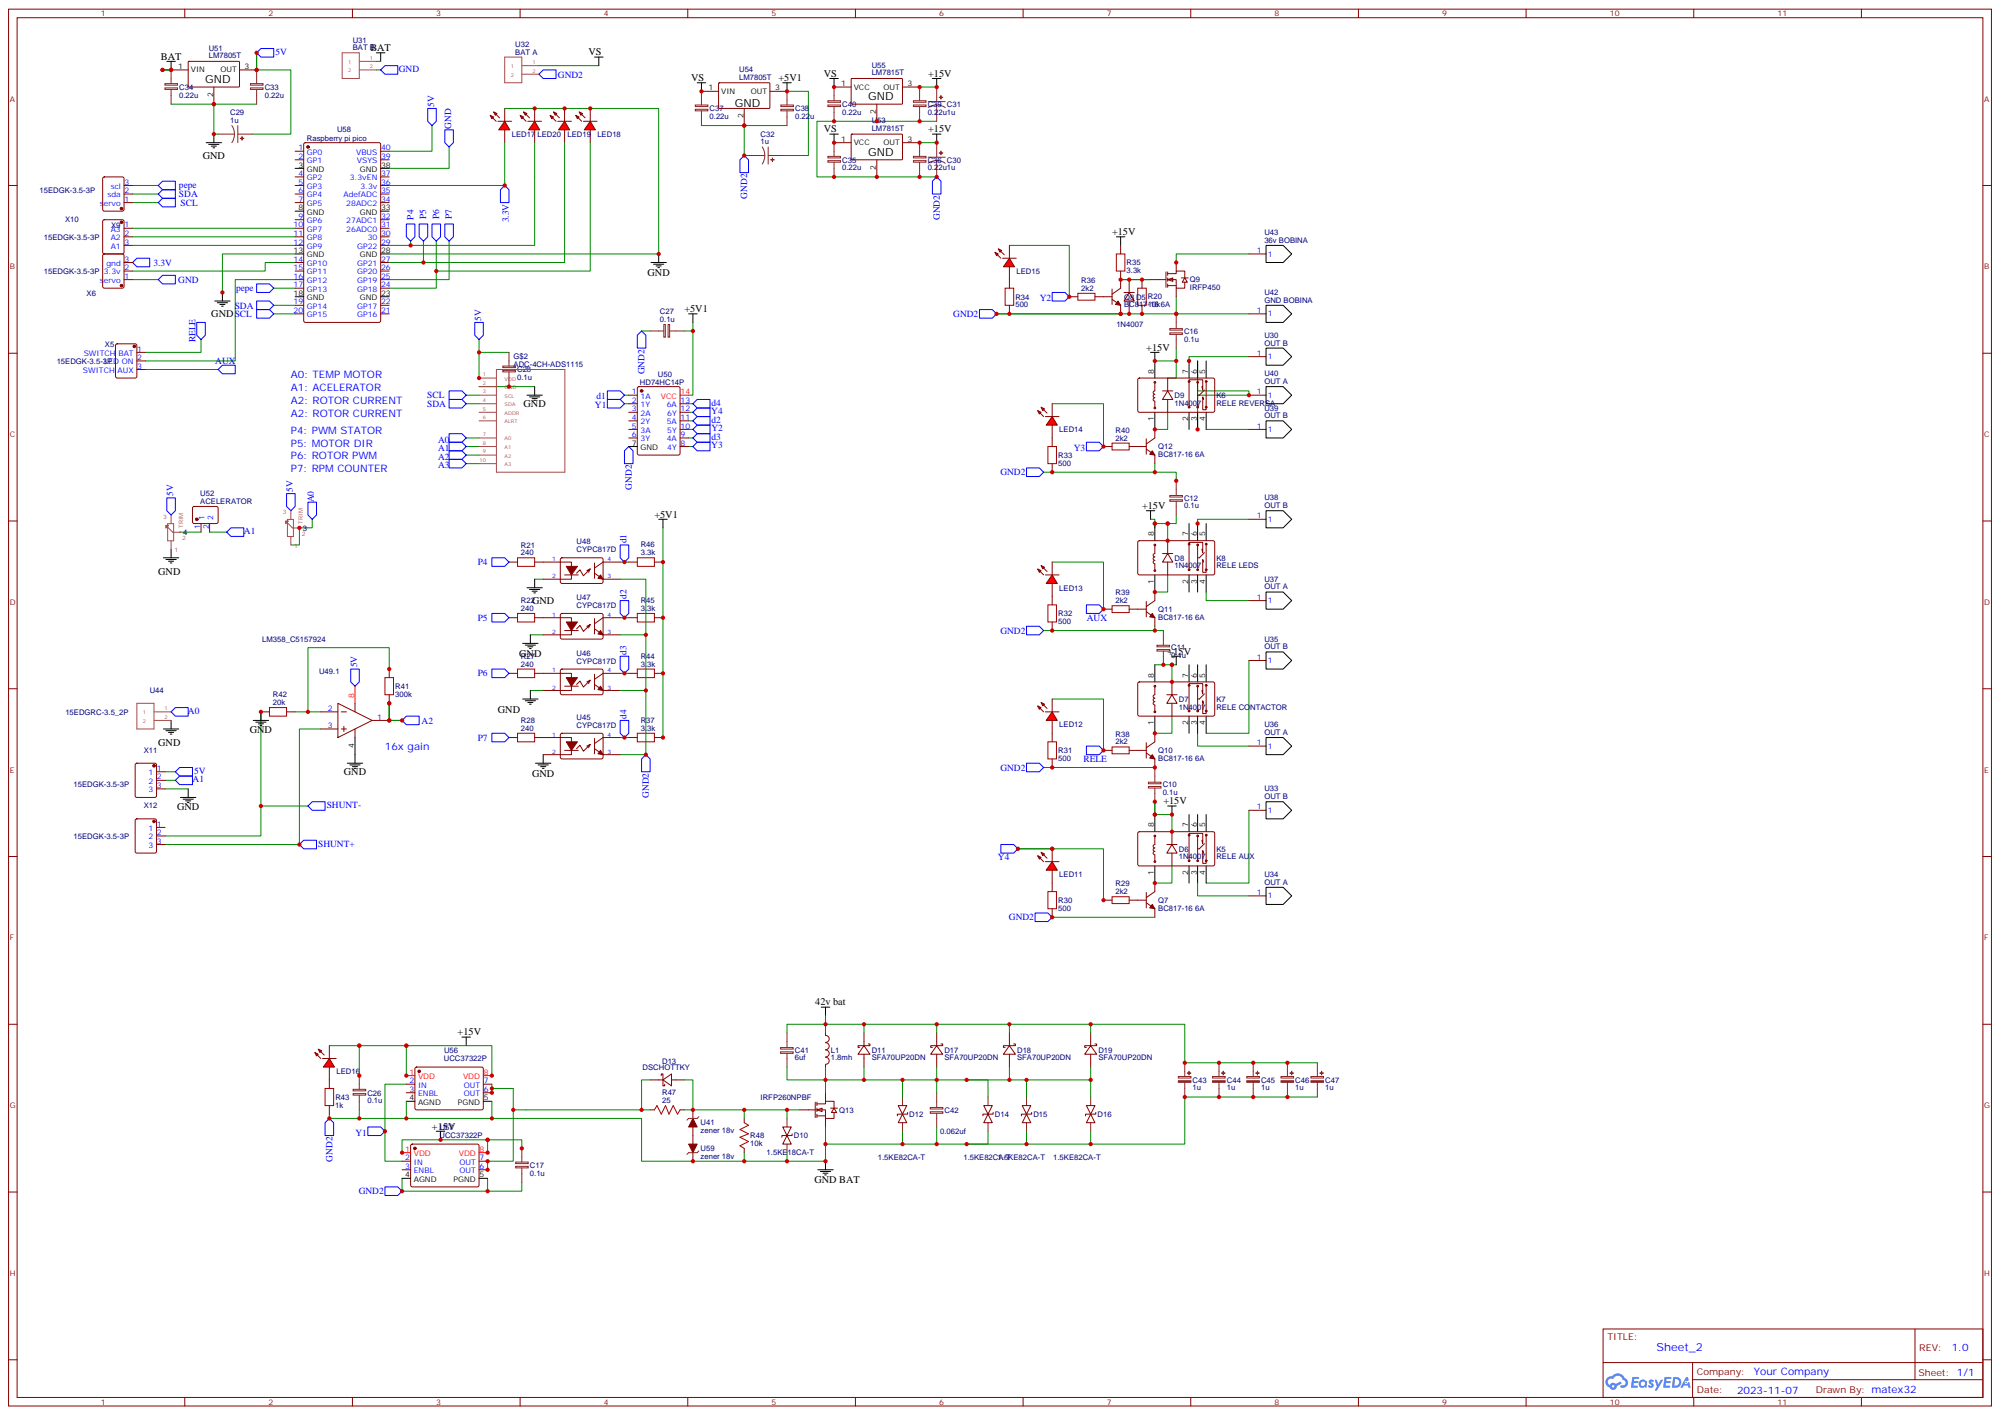
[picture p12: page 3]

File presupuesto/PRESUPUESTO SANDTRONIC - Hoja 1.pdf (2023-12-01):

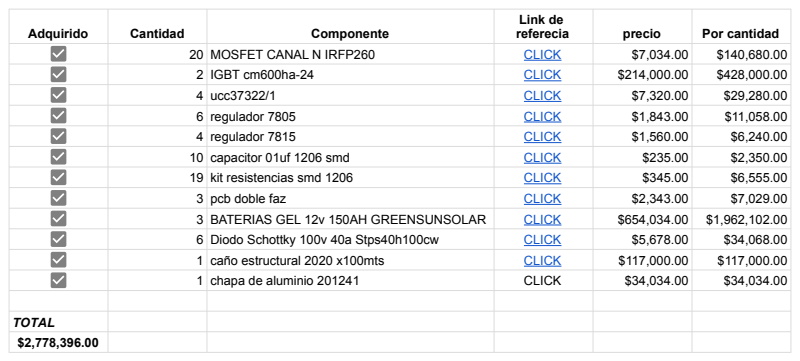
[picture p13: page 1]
Adquirido; Cantidad; Componente; Link de; referecia; precio; Por cantidad; 20 MOSFET CANAL N IRFP260; CLICK; 2 IGBT cm600ha-24; 4 ucc37322/1; 6 regulador 7805; 4 regulador 7815; 10 capacitor 01uf 1206 smd; 19 kit resistencias smd 1206; 3 pcb doble faz; 3 BATERIAS GEL 12v 150AH GREENSUNSOLAR; 6 Diodo Schottky 100v 40a Stps40h100cw; 1 caño estructural 2020 x100mts; 1 chapa de aluminio 201241; TOTAL

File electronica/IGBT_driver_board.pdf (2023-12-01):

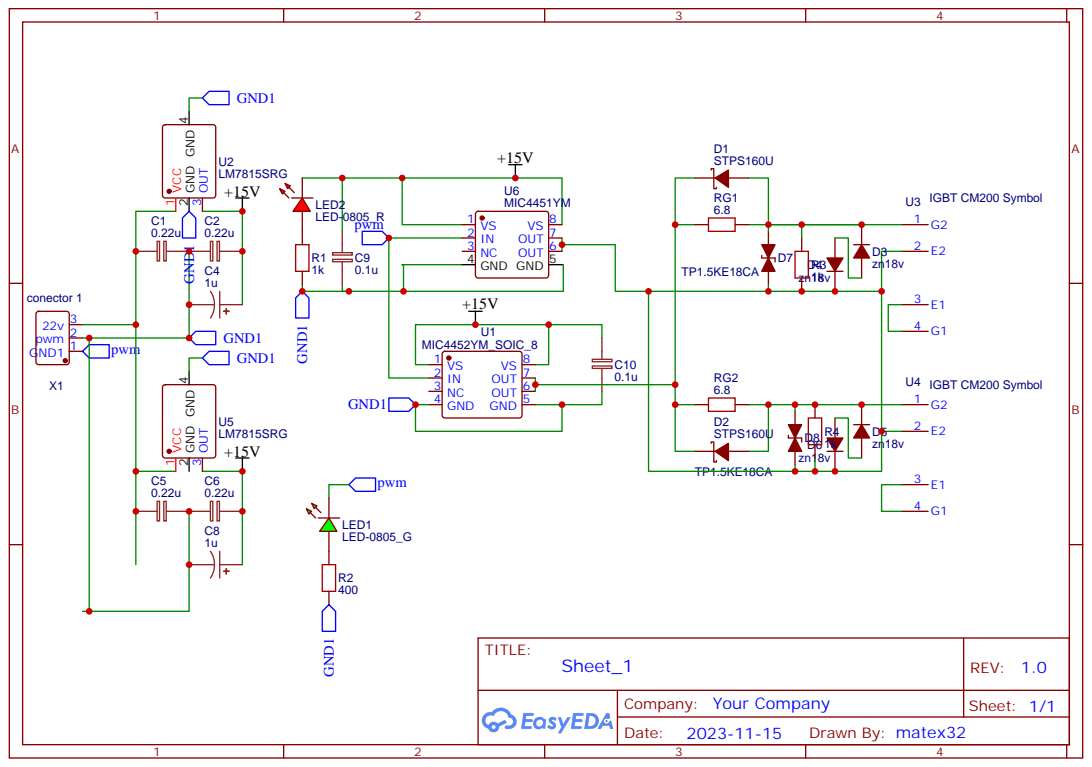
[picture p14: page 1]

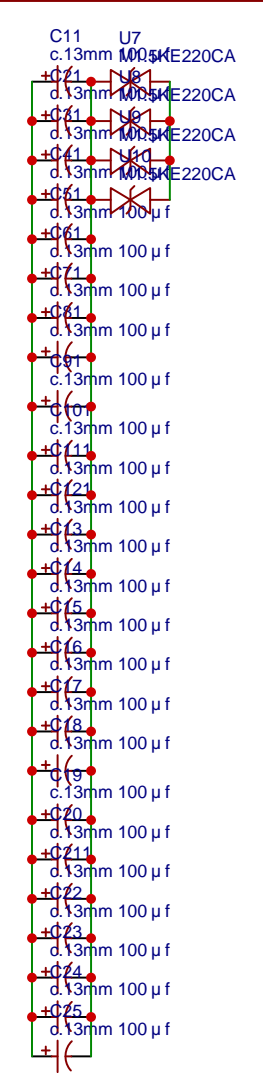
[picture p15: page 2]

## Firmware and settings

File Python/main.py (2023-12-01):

import machine
import utime
import time
import ads1115
import _thread
from machine import Pin, I2C, PWM

### parametros dedicados del pwm rotor 

### multithread para separar el velocímetro del código del acelerador

#print("HOLA")
pin_encendido = Pin(7, Pin.IN, Pin.PULL_DOWN)
pin_a1_reversa = Pin(9, Pin.IN, Pin.PULL_DOWN)
pin_reversa = Pin(21, Pin.OUT)
#pin_led = Pin(12, Pin.OUT)
boton_presionado = None

class rotor(): 
    def __init__(self):               
        self.pwm = PWM(Pin(22)) # pwm del rotor
        self.pwm.freq(2800)

        self.i2c = I2C(1, scl=Pin(15), sda=Pin(14), freq=400000) # direc i2c del adc externo - sensa señal del acelerador 
        self.adc = ads1115.ADS1115(self.i2c, 72, 0) # adc externo

    def map(self, var, low_min, low_max, high_min, high_max):
        low_range = low_max - low_min
        per = var / low_range
        high_range = high_max - high_min
        result = high_range * per
        return int(result)


### parametros y funciones dedicados del velocimetro

class velocimeter():
    def __init__(self):   
        self.servo_pin = 13 # Pin del servo del velocimetro
        self.sensor_pin = 20 # Pin del sensor 

        self.pwm = PWM(Pin(self.servo_pin))
        self.pwm.freq(50)

        self.sensor = Pin(self.sensor_pin, Pin.IN) # sensor de pulsos de motor

        self.pulse_count = 0
        self.speed = 0.0
        self.diametro= 0.55
        self.circunferencia= 0.55 * 3.14
        self.relacion = 8.9
        self.cant_imanes = 4

        self.servo_duty_0 = 8000
        self.servo_duty_180 = 1333

        self.duty = self.servo_duty_0

        self.m = (1333-8000) / 80

    def calculate_speed(self):
        #global pulse_count, speed, duty
        self.speed = self.pulse_count * 10 / (self.relacion * self.cant_imanes) * self.circunferencia * 3.6
        self.duty = int (self.m * self.speed + self.servo_duty_0)
        self.pulse_count = 0
        self.speed_str = "velocidad: {:.1f} km?h" .format(self.speed)
        return self.speed_str

    def on_pulse(self):
        #global pulse_count
        self.pulse_count += 1
        return self.pulse_count

###

def pwm_rotor():
    while True:
        if pin_a1_reversa.value() == 1:
            pin_reversa.value(1)
        else:
            pin_reversa.value(0)
        value = rotor.adc.raw_to_v(rotor.adc.read(7,1))
        reading = value
        res = rotor.map(reading,0,3.3,0,84000)
        if value < 1:
            res = 19500
        print("ADC: ", value)
        print("PWM: ", res )
        rotor.pwm.duty_u16(res - 19500)
        utime.sleep(0.05)

def velocimetro():
    velocimeter.sensor_pin.irq(trigger=machine.Pin.IRQ_RISING,handler=velocimeter.on_pulse)
    t= machine.Timer()
    t.init(period=100, mode=machine.timer.PERIODIC, callback=velocimeter.calculate_speed)

    while True:       
        print(velocimeter.calculate_speed())
        print(velocimeter.on_pulse())
        velocimeter.pwm.duty_u16(velocimeter.duty)

def main():
    print("Start main")
    global rotor
    global velocimeter
    rotor = rotor()
    velocimeter = velocimeter()
    _thread.start_new_thread(pwm_rotor, ())
    velocimetro()
    # safeguard por si se llena la queue de threads, evito crasheos

def boton_encendido():
    global pin_encendido
    #global pin_led
    global boton_presionado
    if pin_encendido.value() == 1:
        if boton_presionado is None:
            boton_presionado = time.ticks_ms()
        else:
            if time.ticks_diff(time.ticks_ms(), boton_presionado) > 2000:
                print("Encendido.")
                #pin_led.value(1)
                main()        
    else:
        print("El botón está en posición de apagado.")
        return

while True:
    #print("Test")
    if pin_encendido.value() == 1:
        print("Encendiendo . . .")
        boton_encendido()

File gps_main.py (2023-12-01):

from machine import Pin, UART
import utime
import time
import _thread
from micropyGPS import MicropyGPS

#test

class sim():
        
    def __init__(self):
        self.uart = UART(0, baudrate=9600, tx=Pin(12), rx=Pin(13))  

        #self.destno = destno
        #self.msg = msg

        self.uart.write('ATE0\n')         # command echo off
        self.uart.write('AT+CRSL=99\n')   # ringer level
        self.uart.write('AT+CMIC=0,10\n') # microphone gain
        self.uart.write('AT+CLIP=1\n')    # caller line identification
        self.uart.write('AT+CMGF=1\n')    # plain text SMS
        self.uart.write('AT+CALS=3,0\n')  # set ringtone
        self.uart.write('AT+CLTS=1\n')    # enabke get local timestamp mode
        self.uart.write('AT+CSCLK=0\n')   # disable automatic sleep

    def send_sms(self, phone_number, message):
        # activa modo sms
        self.uart.write('AT+CMGF=1\r\n')
        time.sleep(1)
        response = self.uart.read().decode('utf-8')
        print(response)
        
        if "OK" not in response:
            print("Fallo al establecer modo texto.")
            return

        # setea número
        self.uart.write('AT+CMGS="{}"\n'.format(phone_number),99,5000,message+'\x1A')
        time.sleep(1)
        response = self.uart.read().decode('utf-8')
        print(response)

        if ">" not in response:
            print("Fallo al establecer número de destino.")
            return

        # envía el mensaje
        self.uart.write('{}\r\n'.format(message))
        time.sleep(1)

        # envía ctrl z para finalizar el envío
        self.uart.write('\x1A')
        time.sleep(1)

        # espera al envío de mensaje
        response = self.uart.read().decode('utf-8')
        print(response)

        if "OK" not in response:
            print("Fallo al enviar SMS.")
        else:
            print("SMS enviado con éxito.")


class gps_custom():

    def __init__(self): # Inicializar modulo GPS
        self.gps_module = UART(1, baudrate=9600, tx=Pin(8), rx=Pin(9))
        time_zone = -3
        return time_zone
        
    
    def convert_coordinates(self, sections):
        if sections[0] == 0:  # sections[0] contains the degrees
            return None
    
        # sections[1] contains the minutes
        data = sections[0] + (sections[1] / 60.0)
    
        # sections[2] contains 'E', 'W', 'N', 'S'
        if sections[2] == 'S':
            data = -data
        if sections[2] == 'W':
            data = -data
    
        data = '{0:.6f}'.format(data)  # 6 decimal places
        return str(data)
    
destno = "Número en formato +xxxxxxxxxxx"
msg = "Mensaje, sobreescrito por el loop del programa"
 
time_zone = gps_custom()
gps = MicropyGPS(time_zone)
sim()

while True:
    length = gps_custom.gps_module.any()
    if length > 0:
        data = gps_custom.gps_module.read(length)
        for byte in data:
            message = gps_custom.update(chr(byte))
 
    latitude = gps_custom.convert_coordinates(gps.latitude)
    longitude = gps_custom.convert_coordinates(gps.longitude)
 
    if latitude is None or longitude is None:
         print("Data no disponible")
         print("No hay coordenadas")
         continue
    print('Lat: ' + latitude)
    print('Lon: ' + longitude)
    msg = ('Lat: ' + latitude + " Lon: " + longitude)
    sim.send_sms(destno, msg)

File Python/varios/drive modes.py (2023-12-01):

import machine
import utime
import time
import ads1115
def map(var, low_min, low_max, high_min, high_max):
    low_range = low_max - low_min
    per = var / low_range
    high_range = high_max - high_min
    result = high_range * per
    return int(result)

from machine import Pin,I2C, PWM
a1 = PWM(Pin(21))
a2 = PWM(Pin(19))
sw1 = PWM(Pin(3))
sw2 = PWM(Pin(4))
sw3 = PWM(Pin(5))

pwm = PWM(Pin(21))
pwm.freq(1500)

i2c = I2C(1, scl=Pin(15), sda=Pin(14), freq=400000)
adc = ads1115.ADS1115(i2c, 72, 0)


while (1):
    
    
    
    value = adc.raw_to_v(adc.read(7,1))
    reading = value
    
    res = map(reading,0,3.3,0,84000)
    if value < 1:
        res = 19500
    print("ADC: ", value)
    print("PWM: ", res )
    pwm.duty_u16(res - 19500)
    utime.sleep(0.05)

    

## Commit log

2023-10-20 feat: agregar modelo de pagina web
2023-10-21 feature: add main program
    Codigo base, sensa la señal del acelerador y entrega una señal PWM
2023-10-30 Codigo acelerador PWM
    genera una señal pwm en base a la posicion del pedal de aceleracion
    [Magnet support v1 v1.stl, SOporte cooler motor v2 v1.stl, Soporte servo motor v1.stl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]
2023-10-30 Borre todo man
    [Magnet support v1 v1.stl, SOporte cooler motor v2 v1.stl, Soporte servo motor v1.stl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]
2023-11-08 feat: crear main
    Cree un main para la programacion del modulo GSM
2023-11-08 feat: crear test de modulo GSM
2023-11-08 feat: agregar codigo funcional
    testeo de capacidad de envio del mensaje
2023-11-08 feat: agregar libreria
    libreria: https://github.com/Ircama/raspberry-pi-sim800l-gsm-module
2023-11-08 build: cambio de libreria sim800l
    cambie la libreria por incompatibilidad con upython
    [mainGSM.py, sim800l.py]
2023-11-09 chore: agregar programa sin libreria
    las incompatibilidades de las librerías anteriores me forzó a probar otro código
    [mainGSM.py, sim800l.py]
2023-11-10 chore: continuar debug, no anda la conexion al numero
2023-11-10 update: modify "drive modes" (main code)
    Actualizo el codigo con lo trabajado desde Thonny
2023-11-10 chore: change pins
    Ademas arreglo typo en el while
    [VELOCIMETRO SANDTRONIC THONNY.py, main.py]
2023-11-10 feature: merge main, velocimeter codes
    Implementacion de multithreading. Arreglados varios typos en el codigo del velocimetro
    [VELOCIMETRO SANDTRONIC THONNY.py, main.py]
2023-11-10 feature: implement code as objects
    Convierto setup del velocimetro y del pwm del estator en clases
2023-11-10 fix: fix declaration typos
    Llamo a las clases del estator y el velocimetro en el main y declaro las variables de las clases en el codigo principal
    [main.py]
2023-11-10 feature: unir el codigo del gsm y el gps
    Funcionalidad gps y gsm en clases.
    Incluyo refactor de carpetas, ignorar el legacy
2023-11-10 fix: arreglar incompatibilidad de declaraciones
    Resuelto conflicto al usar el mismo nombre para la clase de la librería micropyGPS con el de la clase gps del main
    [gps_main.py]
2023-11-10 fix: era rotor, no estator
    [main.py]
2023-11-10 test de commit
2023-11-11 fix: add interrupt for velocimeter
    El velocimetro no andaba porque no estaba codeada la interrupcion. Ejecuto la funcion del velocimetro en main para poder evitar problemas de management de memoria al ejecutar interrupciones adentro del thread
    [TEST MULTI THREADING.py, VELOCIMETRO SANDTRONIC THONNY.py, drive modes.py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]
2023-11-11 fix: fix while loop conflict
    Arreglo problema por conflicto de whiles, la mitad del main no se ejecutaba. Agrego boton de encendido
    [main.py]
2023-11-11 fix: arreglar problemas de comando de sim
    [gps_main.py, mainGSM.py]
2023-11-11 fix: add working pwm
    El pwm funciona nashei
    [main.py, sensor_pulsos.py]
2023-11-11 feature: add reverse mode
    Ahora el terreneitor va en reversa
    [main.py]
2023-11-15 docs: imagen de la institución
2023-11-15 docs: modifique la imagen
2023-11-15 docs: cambio de fondo del qr
2023-11-15 docs: arreglo de imagen
2023-11-15 docs: cambio en el texto
2023-11-15 docs: cambio en el titulo
2023-11-16 docs: arreglo de texto
2023-11-23 feat:añadir velocimetro
    añadir codigo velocimetro en proceso
2023-11-23 fix:añadir class que calcula pulsos
    se agrega cuales son los valores quee debe calcular en una ventana de tiempo para poder hacer el calculo de velocidad
    [velocimetro_class.py]
2023-11-23 fix: agregar def iniciar
    [velocimetro_class.py]
2023-11-23 fix: agregar def calculate_speed
    se agregan las lineas de codigo las cuales calculan velocidad en km/h
    [velocimetro_class.py]
2023-11-23 fix: agregar print
    se agrega keyboardinterrumpt para darle stop al programa
    [velocimetro_class.py]
2023-11-23 feature: añadir codigo de modos
    en este codigo se nombran los modos de conduccion de sandtronic
2023-11-23 fix: modos y estados de sandtronic
    [sandtronic_prueba.py]
2023-11-23 fix: acel y freno
    [sandtronic_prueba.py]
2023-11-23 fix: agregar print´s
2023-11-24 docs: presentación
    Se sube el link de la presentación de canva
2023-11-24 docs: subir pdf de presentación
2023-11-24 docs: cree carpeta para unir documentación
    movi de lugar la presentación
2023-11-24 documentation: agregar diagrama v3 placa de control
2023-11-24 documentation: agregar esquematico de la placa de control
2023-11-24 documentation: agregar diagrama de placa de potencia
2023-11-24 documentation: agregar esquematico placa de potencia
2023-11-24 update: agregar esquematico nuevo de la placa de potencia
2023-11-24 refactor: agregar carpeta de circuitos y esquematicos
2023-11-24 docs: elimino esta carpeta
    acomodo todo en la nueva branch creada
2023-11-24 docs: agregar presentacion
    pase de branch la presentación
2023-11-24 docs: arreglos en la rama
2023-11-24 docs: elimino la presentación del readme
2023-11-24 fix:añadir def medidor autonomia
    [autonomia.py]
2023-11-24 fix: añadir adc valor voltaje
    [autonomia.py]
2023-11-24 fix: voltaje
2023-11-24 feature: añadir core
    agrego el codigo que divide tarea en el micro por nucleos para no saturarlo
2023-11-24 fix:agregar core 0
    tareas al primer nucleo
    [core.py]
2023-11-24 docs: agrego banner
    agregue banner y elimino el de ejemplo
2023-11-24 feat: agregar manual de usuario
2023-11-24 documentation: añadir carpeta de campo
    Carpeta tecnica finalizada
2023-11-24 docs: agregar facturacion
    mosfets
    micro
    terminales
2023-11-24 documentation: añadir manual de usuario
    Manual de usuario finalizado
2023-11-24 docs: agregar presupuesto final
    recuento de gasto total en sandtronic
2023-12-01 docs: agrego los 3d
    arregle los nombres y subo los 3d de la placa de potencia y control
2023-12-01 docs: convierto a pdf el manual de usuario
2023-12-01 docs: cambio de lugar la carpeta tecnica
2023-12-01 docs: elimino de esta rama la documentacion vieja
2023-12-01 docs: cambio de lugar manual de usuario
2023-12-01 docs: cambio en el readme

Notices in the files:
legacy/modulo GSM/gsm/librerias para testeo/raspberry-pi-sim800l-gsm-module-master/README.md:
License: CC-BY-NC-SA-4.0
